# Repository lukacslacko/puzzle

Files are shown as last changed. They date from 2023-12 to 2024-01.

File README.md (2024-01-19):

# Jigsaw dissections

## Motivation

> [!IMPORTANT]
> Read the dissections books of Greg N. Frederickson! All of them! They are amazing!

Square to triangle
Two squares to one

Motivated by the books of Frederickson I wanted to produce polygon dissections physically, especially hinged ones, as they looked particularly neat. However 3D printing a good hinge mechanism is not easy. Chapter 22 of "Hinged Dissections: Swinging & Twisting" describes how to turn hinges into twist hinges which rotate 180 degrees, which seemed easier to produce. Then I thought that a symmetric jigsaw connection corresponds to a twist hinge, thus replacing twist hinges with jigsaw connections produces dissections which look nice and remain stuck together.

## Goals and non-goals

Things I care about:
 * Easy 3D printing
    * In particular, the size of the smallest detail should be as large as possible.
    * Avoiding sharp angles, with which the circular (rather than linear) connector pieces help quite a bit, since they produce right angles where they meet the edges.
 * Symmetric look
 * Relatively easily putting together the puzzle. Using circular hinge connectors guide the puzzler in finding which piece fits where. Having some pieces have outwards tabs and some inwards tabs further help with this.
 * Solid, non-flimsy results

Things I don't really care about:
 * Using few pieces for a dissection
 * Whether pieces are flipped during the dissection (when pieces are physically made from homogeneous 3D filament, they look roughly the same on both sides anyway)
 * Direction of grain (again, with 3D printing there is not really such a notion and I don't own a laser cutter)

## Turning any dissection into a jigsaw one

Since any two polygons of the same area can be dissected into each other, it is a question whether any pair can be jigsaw dissected. Using an edge connector to glue together edges which touch when either polygon is constructed from the pieces, one can produce a jigsaw dissection between any two polygon with the same area. This dissection will be rather boring, however, since all the connectors will be symmetric pieces and always in the middle of the edges.

Edge connection

## Turning hinged and twist hinged dissections into a jigsaw one

Snug hinges (defined in Chapter 2 of Frederickson's "Hinged Dissections: Swinging & Twisting" as hinges which rotate completely from one end state to the other) can be converted to twist hinges and thus jigsaw dissection like this:

Hinge connector

Hinge connectors can be of any symmetrical shape, they don't need to be linear or circular, nor do the jigsaw connection need to be circular, as long as they are symmetrical. For simplicity though and nice looks, I prefer these shapes.

One advantage of jigsaw dissections is that often hinged dissections could go "all the way around", but for physical realization one hinge needs to be removed, which, then, after completely hinging the dissections around, meets up again. With jigsaw dissections, such hinged dissections could be fully "jigsawed", which makes the resulting product stable, rather than wanting to become unhinged and swing between the two end states, as it happens with hinged dissections.

Twist hinges, which are standalone 180 degree rotations along an axis perpendicular to the common edge of the two pieces, directly correspond to a jigsaw connection:

Flip connector

## Overlaying dissections

When one wishes to produce dissections among multiple polygons, one way to achieve that is to overlay multiple dissections. In such cases when external edges of two polygons intersect, one needs to insert a connector structure which holds the pieces together, with a flush outer edge, along either of the two intersecting polygon edges. This can be achieved like this:

Cross connector
Cross connector

## Examples

These dissections are based on the ideas from the Frederickson books. Buy them and read them, they are really, really great.

### Two equal squares to one

Two equal squares to one

### Square to regular triangle

Square to triangle
Square to triangle

### Square to regular octagon

Square to octagon

### Square to cross

Square to cross

Note that hinge connector pieces don't need to have the same radius as long as each segment is symmetric.

### Square to 8/3 star

Square to star

Note that internal five pieces don't strictly need the hinge connectors, but to keep the puzzle nicer together (to have fewer pieces slide along each other) and to increase the symmetry and thus helping when physically putting the puzzle together, by guiding the puzzler showing which piece fits where, I've added them.

### Square, regular triangle and regular octagon

Note that I've chosen a square-triangle dissection which is based on a Q-swing (see Chapter 3 of "Hinged Dissections"), in order to increase the size of the smallest piece and to keep the dissection more symmetric, at the cost of increasing piece count.

Sqaure, triangle, octagon

Square, triangle, octagon

Square, triangle, octagon

Note that without the small linear tabs between R - T_R and S - T_S (that is, when one would have simple lines between these points) one would get two halves of the regular triangle with completely flush edges, nothing to hold them together, so while they are breaking the complete symmetry of the dissection, they are needed to hold the triangle together.

Note that at IX and its centrally symmetric partner we needed to add a cross connector structure, since IX is both on the outer edge of the triangle and the octagon, and without a connecting piece there, the polygons would slide apart.

Also note that while the outer edges of the octagon and the triangle also intersect at points IY and IZ, but we don't actually need cross connector pieces there (which would end up being really tiny, IY being so close to W) because luckily the cross connector around IX and its symmetric partner hold everything together.

### Square to pentagon

Square to pentagon

## Considerations for 3D printing

I've used OpenSCAD to print the pieces for these dissections, with a small offset of about -0.07 millimeters and a linear extrusion of 4 millimeters, resulting neat, snug jigsaw pieces which hold together well.

## The code

I've used complex numbers to produce the dissections, since they very naturally lend them to such a task and Python has built in support for them, allowing very compact writing of planar locations, rotations, scaling and translation.

I've written a very narrow SVG library to render these, and to render the names of points, to help during the production of the dissection.

## Questions, comments

If you like these, have any ideas or are curious about some other puzzles I've made, either look in the `old` directory or contact me at lukacslacko@gmail.com.

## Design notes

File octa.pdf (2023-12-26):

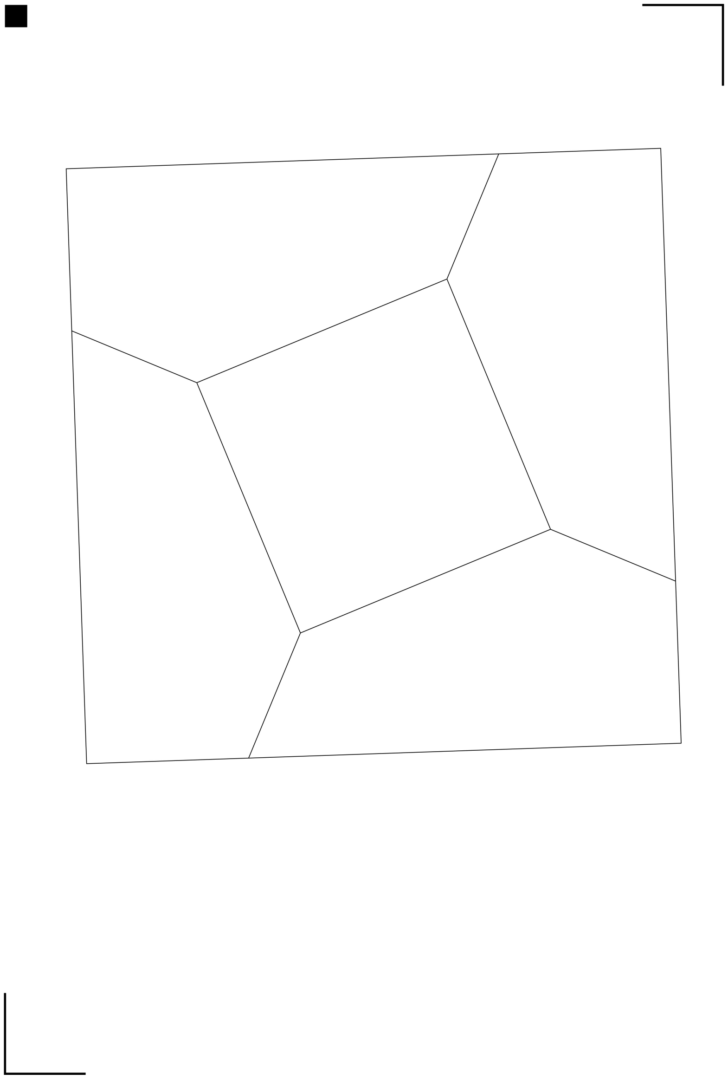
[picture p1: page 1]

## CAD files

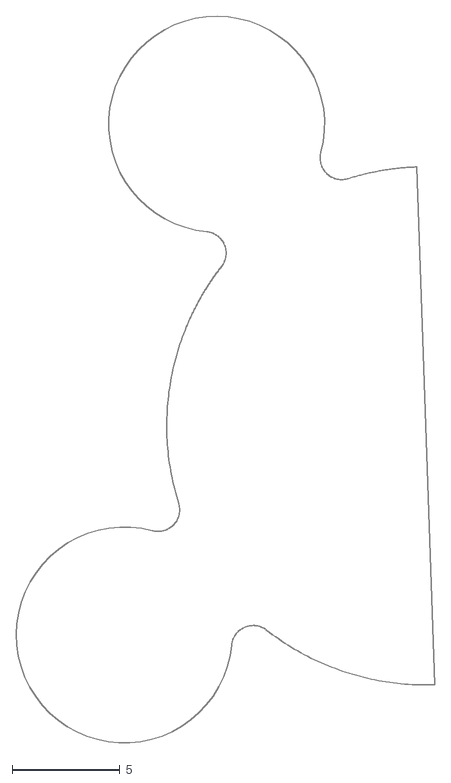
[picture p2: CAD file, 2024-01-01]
438n.dxf
19.4 x 33.7

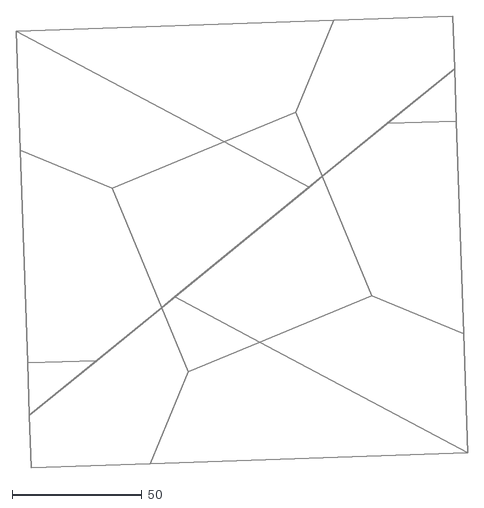
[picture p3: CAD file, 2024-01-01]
simple-sq-3-8-all.dxf
173.9 x 173.9

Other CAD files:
square-triangle-b-4.dxf
square-triangle-b-1.dxf
square-triangle-6.dxf
square-triangle-4.dxf
square-triangle-5.dxf
square-triangle-1.dxf
square-triangle-b-5.dxf
square-triangle-b-0.dxf
square-triangle-7.dxf
square-triangle-b-2.dxf
square-triangle-0.dxf
square-triangle-3.dxf
square-triangle-b-3.dxf
square-triangle-2.dxf
two-squares-1.dxf
two-squares-0.dxf
4--8-2-a.dxf
4--8-2-b.dxf
4--8-2-c.dxf
438a.dxf
438b.dxf
438c.dxf
438d.dxf
438e.dxf
438f.dxf
438g.dxf
438h.dxf
438i.dxf
438j.dxf
438k.dxf
438l.dxf
438m.dxf
linear_tab.dxf
old/4--8-2-a.dxf
old/4--8-2-b.dxf
old/4--8-2-c.dxf
old/438a.dxf
old/438b.dxf
old/438c.dxf
old/438d.dxf
old/438e.dxf
old/438f.dxf
old/438g.dxf
old/438h.dxf
old/438i.dxf
old/438j.dxf
old/438k.dxf
old/438l.dxf
old/438m.dxf
old/linear_tab.dxf
old/simple-sq-3-8-0.dxf
old/simple-sq-3-8-1.dxf
old/simple-sq-3-8-10.dxf
old/simple-sq-3-8-11.dxf
old/simple-sq-3-8-12.dxf
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

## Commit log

2023-12-26 sq 3 8
    [sq-3-8-a.dxf, sq-3-8-b.dxf]
2023-12-26 simple poly
    [sq-3-8-0.dxf, sq-3-8-1.dxf, sq-3-8-10.dxf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]
2023-12-26 context manager
    [438a.dxf, simple-sq-3-8-0.dxf, simple-sq-3-8-1.dxf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]
2023-12-31 edge glue
2024-01-01 octa square hinge
2024-01-01 sq-tri hinge
2024-01-01 sq 3 b
    [438n.dxf, simple-sq-3-8-all.dxf]
2024-01-02 move things around
    [4--8-2-a.dxf, 4--8-2-b.dxf, 4--8-2-c.dxf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]
2024-01-02 Cross connector
